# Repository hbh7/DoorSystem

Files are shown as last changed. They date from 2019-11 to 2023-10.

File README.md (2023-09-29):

# DoorSystem
Code to make a "smart" door locking system that you can use to unlock your door with your phone, as well as see the current weather conditions.

Designed by [hbh7](http://github.com/hbh7) and [alexboz](http://github.com/alexboz)

Features include:
- Non-intrusive design that doesn't require any modifications to the door itself. Perfect for dorms, apartments, and rentals. 
- Minimal hardware requirements - all you need is a Raspberry Pi, Arduino, and a servo. Optionally, you can get POE to USB adapters for long range power like as seen in the pictures. V3 also used a breadboard and capacitors to smooth out some voltage drop issues. You can also get the camera module and 3.5" touch screen for full functionality. 
- Peephole camera that can be broadcast over the network for remote viewing.
- Automatic unlocking followed by relocking after 15s using the timer button. 
- Background color shifts throughout the day to simulate day/night.
- Servo is disabled when the door is locked so that it can still be manually operated using the key, otherwise the servo would probably overpower your attempts.  

Potential areas of improvement:
- Convert 4th button to a camera viewer
- Run the servo closer to 7v instead of 5v for better performance.
- Single power cord option with a better POE adapter.
- Proper cases for everything to contain hardware and manage wires better.

Touch screen and web UI:
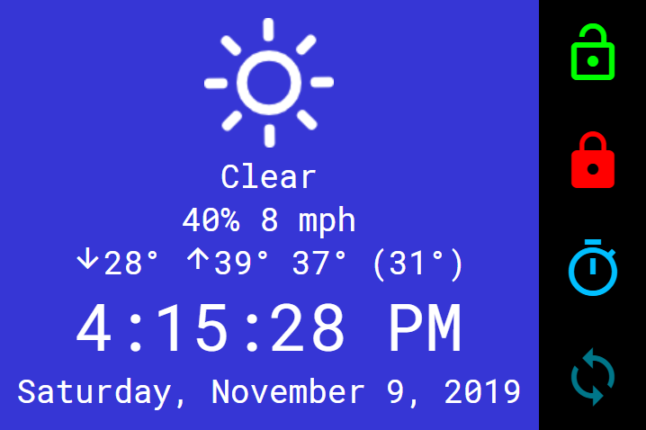
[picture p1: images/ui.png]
Touch screen and web UI


Implementation v3:
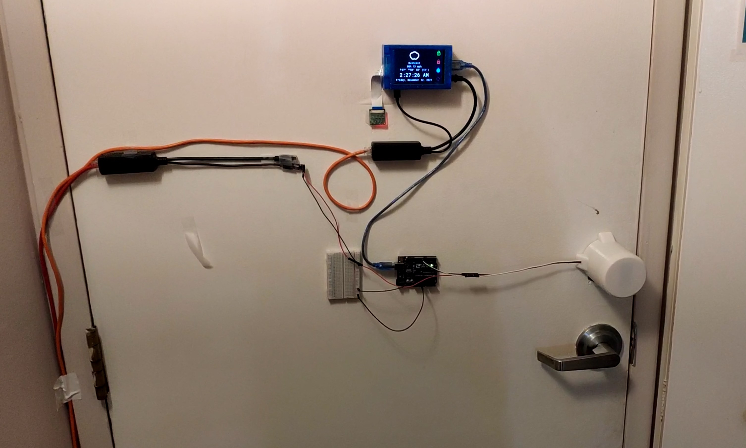
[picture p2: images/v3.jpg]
Implementation 3


Implementation v2:
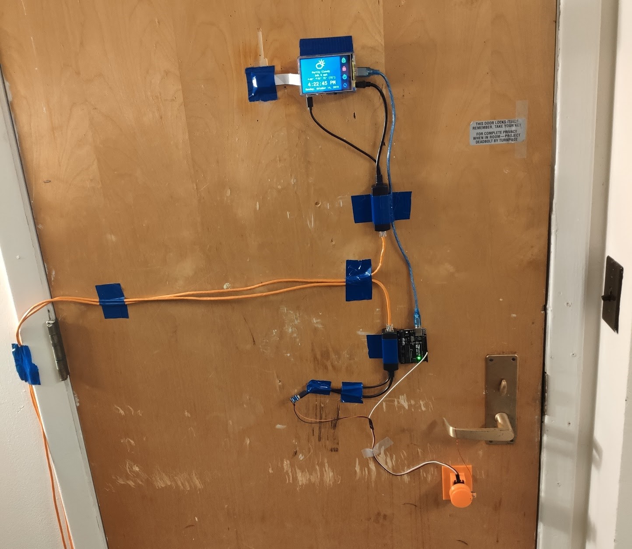
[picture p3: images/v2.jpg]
Implementation 2


Implementation v1:
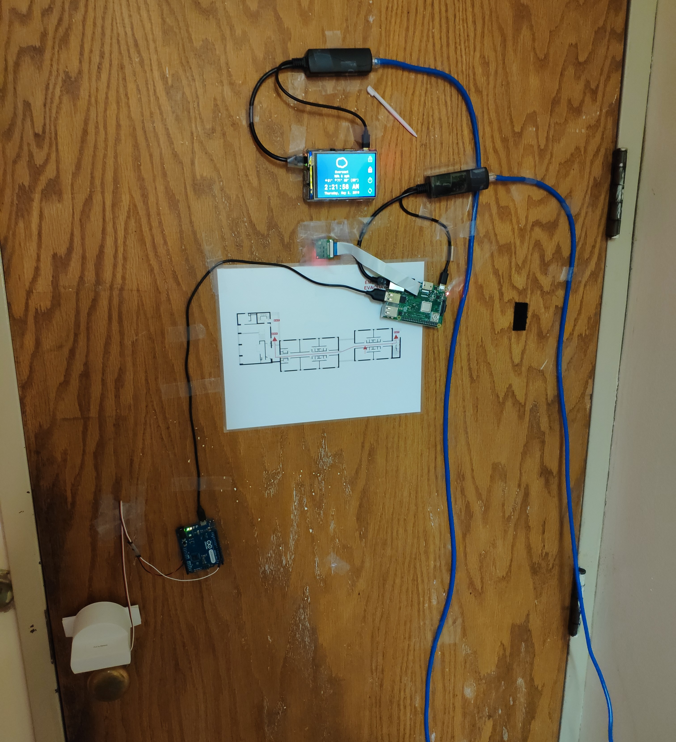
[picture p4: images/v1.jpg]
Implementation 1


## General setup directions
1. You'll want to acquire hardware and familiarize yourself with the software. The exact model of Pi, Arduino, servo, screen, camera, etc. does not matter.  
2. The Pi should run [doorlock-arduino-server.py](backend/doorlock-arduino-server.py) with Python 3, ideally started automatically with something like a systemd service. 
3. The Pi should also serve the html folder using a PHP-capable webserver like Apache. 
4. The Pi's desktop can be configured to automatically launch a fullscreen kiosk browser to the locally served files for display on the screen. This varies by desktop environment. 
5. The Arduino needs the code in [Arduino_Servo_Controller_Sketch.ino](Arduino_Servo_Controller_Sketch/Arduino_Servo_Controller_Sketch.ino) written to it. This enables serial communication to the Pi and drives the servo. Adjust the code as necessary to specify your servo pin and servo angle to match your door lock setup. This will take some trial and error. 
6. You'll also need to 3D model and print your own adapter to match your lock and servo. There are a bunch of examples in the [models](models) folder. 
7. For the webcam, I used https://github.com/jacksonliam/mjpg-streamer. You could use this, or a number of other libraries. This may vary based on your camera choice. 
8. Feel free to open an issue or something if you're having trouble. Good luck!

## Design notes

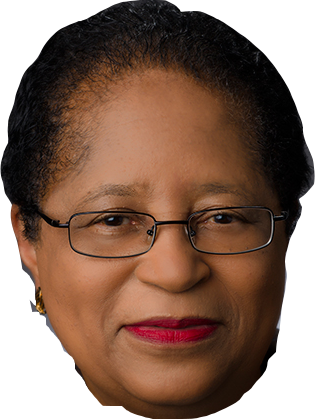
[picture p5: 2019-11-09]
html/shirley.png

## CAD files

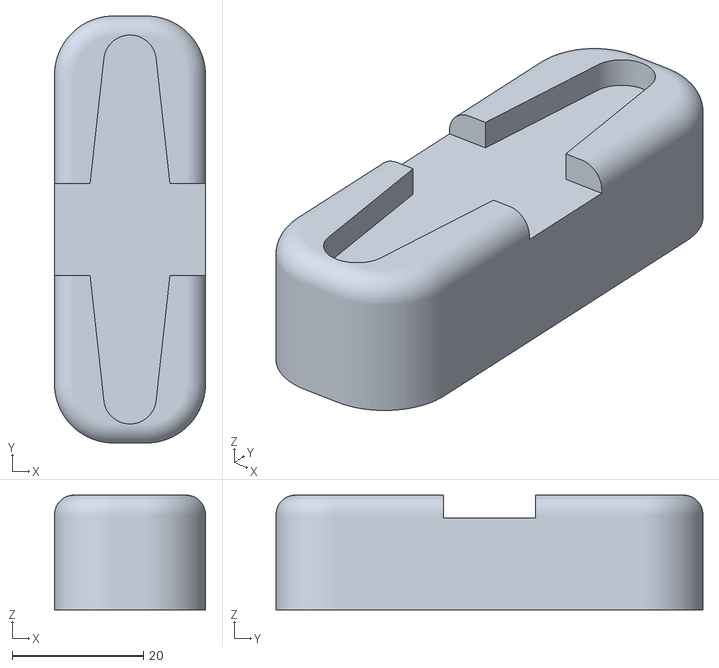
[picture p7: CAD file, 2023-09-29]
models/lock_adapter_modded.stl
23.0 x 65.0 x 17.5

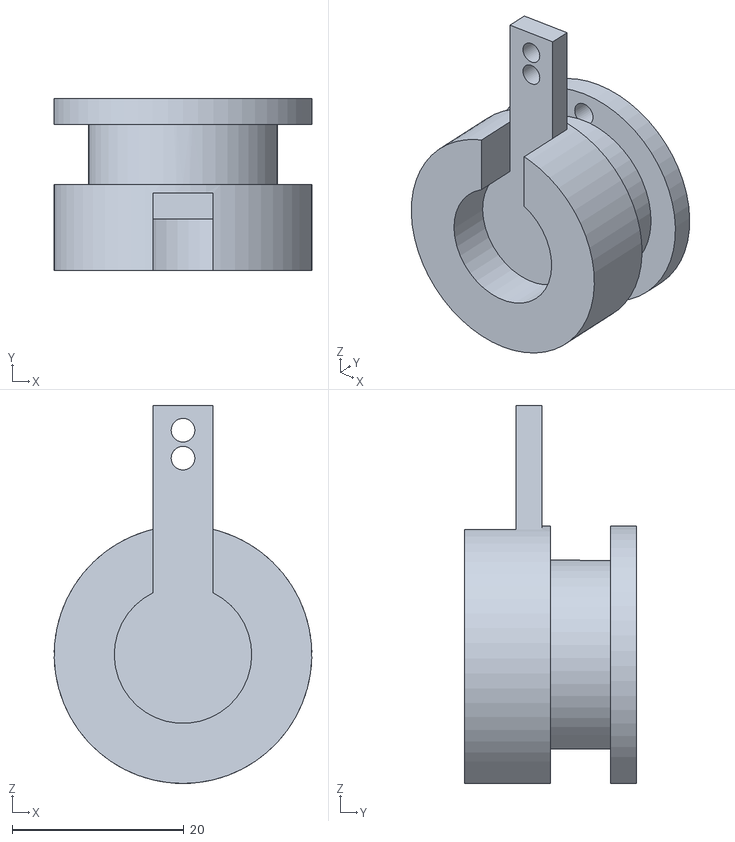
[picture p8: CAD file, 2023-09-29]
models/Servo Wheel 3.STL
30.0 x 20.0 x 44.0

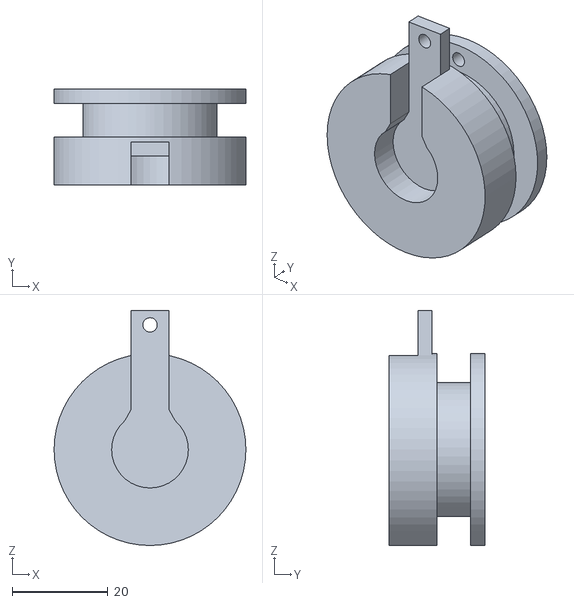
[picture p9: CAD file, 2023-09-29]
models/Servo Wheel 6.STL
40.0 x 20.0 x 49.0

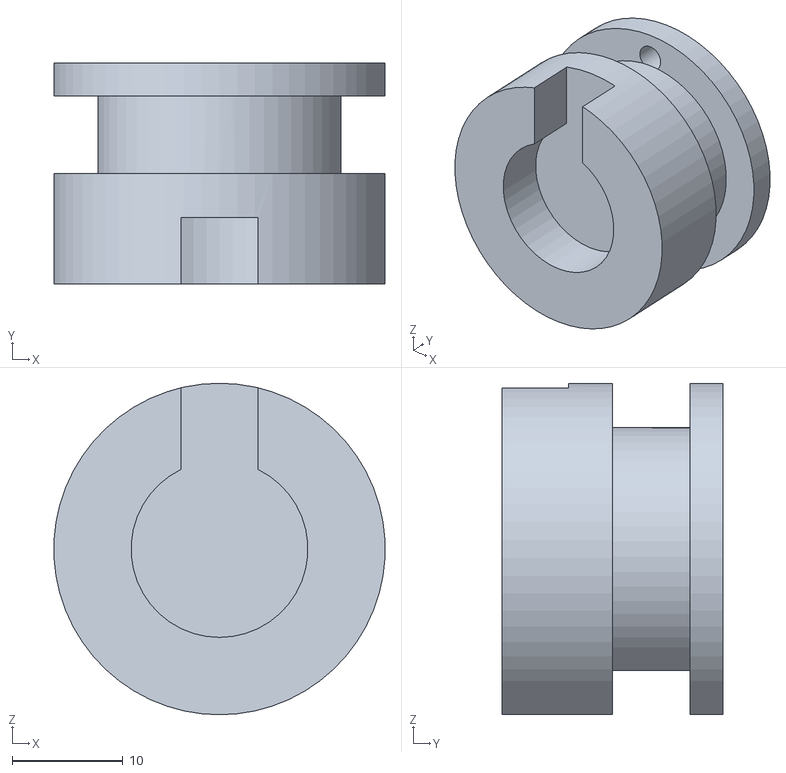
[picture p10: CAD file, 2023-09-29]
models/Servo Wheel 2.STL
30.0 x 20.0 x 30.0

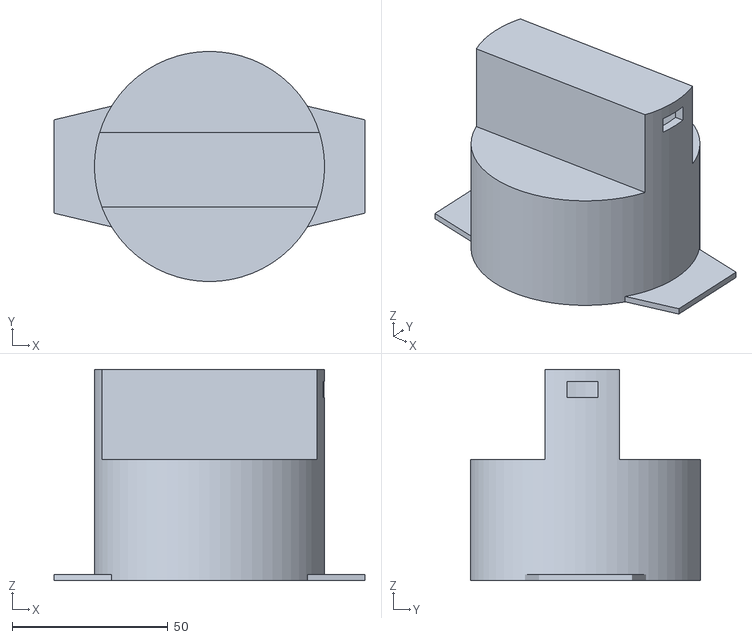
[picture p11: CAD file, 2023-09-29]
models/Door Adapter.stl
100.0 x 74.0 x 68.0

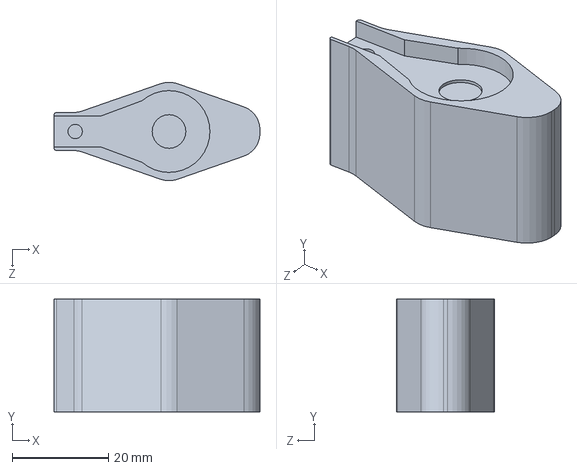
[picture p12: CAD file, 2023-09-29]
models/Door Lock Adapter.SLDPRT
42.8 x 23.4 x 20.4 mm

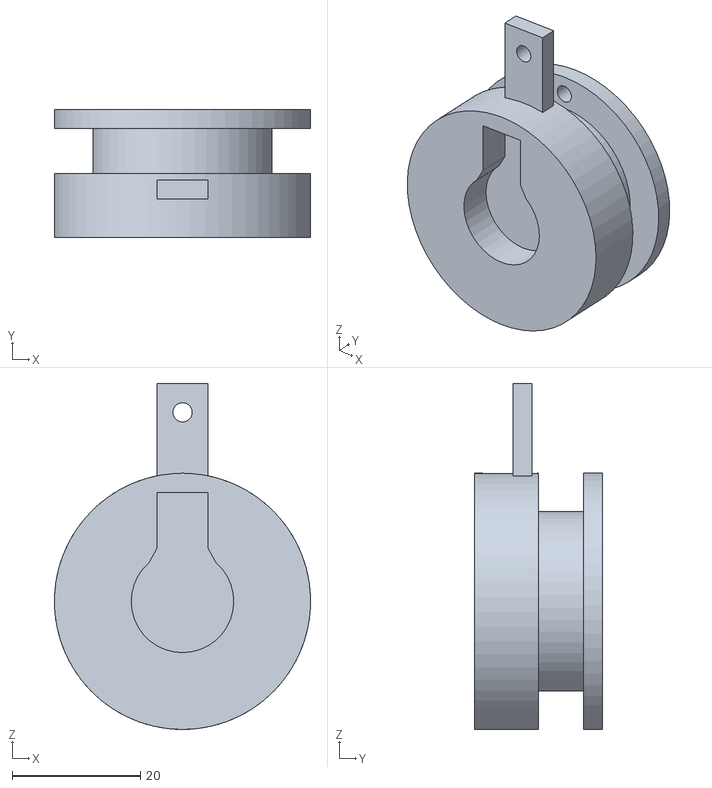
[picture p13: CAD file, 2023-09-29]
models/Servo Wheel 5.STL
40.0 x 20.0 x 54.0

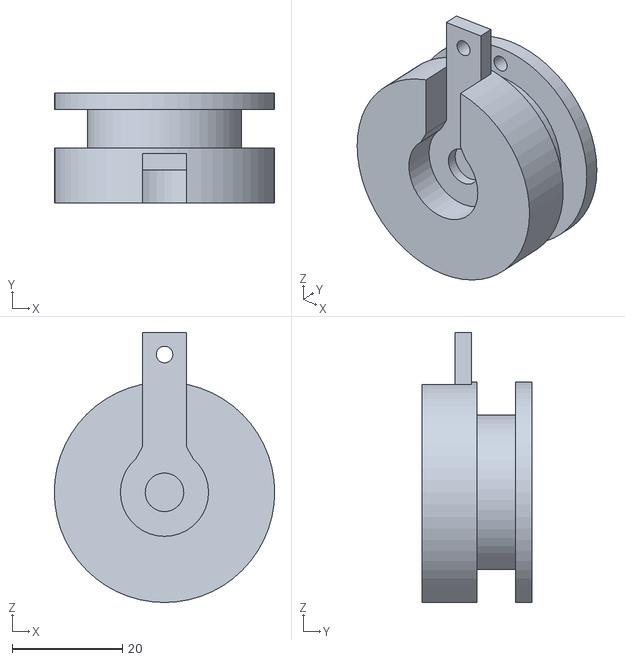
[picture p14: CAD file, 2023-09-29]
models/Servo Wheel 7.STL
40.0 x 20.0 x 49.0

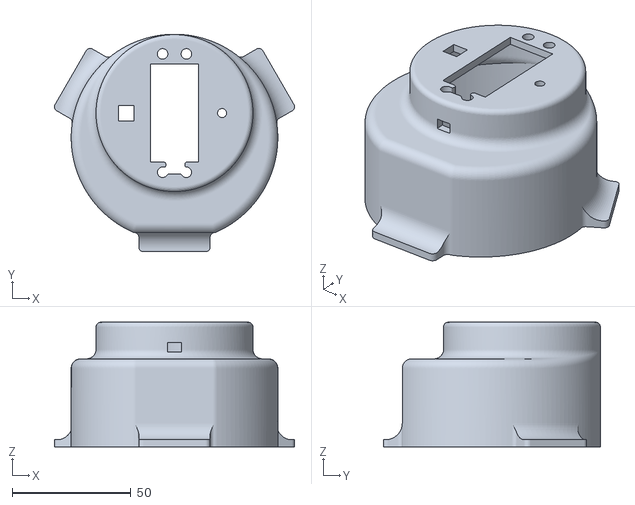
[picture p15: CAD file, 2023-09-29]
models/lock_housing.stl
100.9 x 91.5 x 52.4

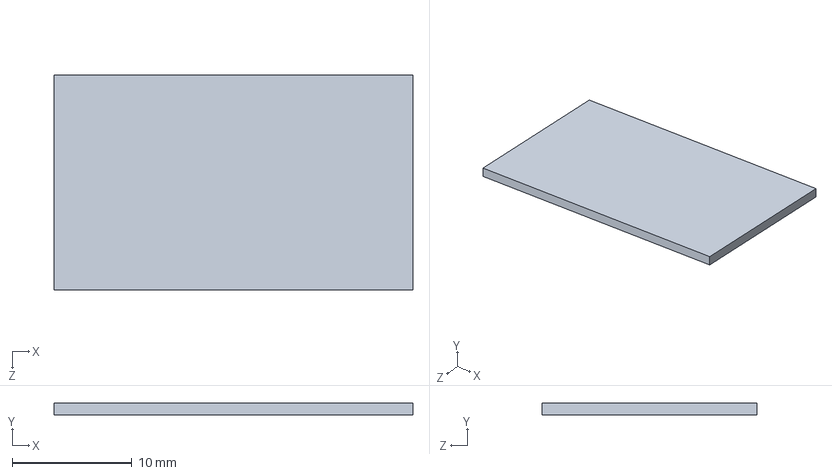
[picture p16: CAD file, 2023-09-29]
models/Pi Screen Spacer.SLDPRT
30.0 x 1.00 x 18.0 mm

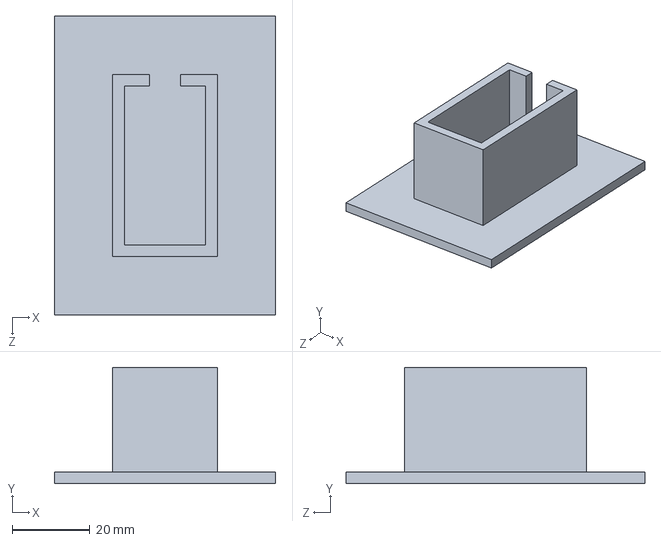
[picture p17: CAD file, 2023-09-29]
models/Servo Mount 3.SLDPRT
57.0 x 30.0 x 77.0 mm

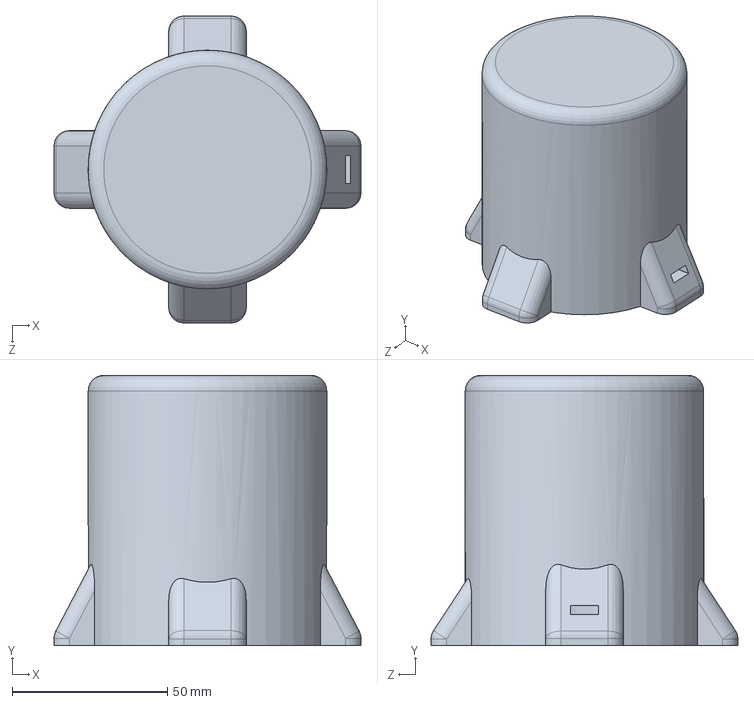
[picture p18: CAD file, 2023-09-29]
models/Servo Housing.SLDPRT
98.8 x 87.0 x 98.8 mm

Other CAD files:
models/Servo Mount 2.SLDPRT
models/Servo Mount.SLDPRT
models/Servo Wheel 4.STL
models/Servo Mount 3-2.STL
models/Servo Mount 2 2.SLDPRT
models/lock_adapter.stl
models/Cup.stl
models/Door Lock Adapter.STL
models/Door Lock.SLDPRT
models/Part4.SLDPRT
models/Pi Screen Spacer.STL
models/Servo Housing.STL
models/Servo Mount 3.STL
models/Servo Wheel 1.STL
models/Servo Wheel.SLDPRT
models/lock_housing 001.3dm
models/lock_housing 002.3dm
models/lock_housing 003.3dm
models/lock_housing 004.3dm
models/lock_housing.3dm

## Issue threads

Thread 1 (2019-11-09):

Occasional temperature rounding error

hbh7, 2019-11-09:

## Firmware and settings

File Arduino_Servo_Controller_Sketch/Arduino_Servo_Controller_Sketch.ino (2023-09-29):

#include <Servo.h>              //Servo library
 
Servo servo;        //initialize a servo object for the connected servo  
                
int angle = 0;    



void setup() {
  // put your setup code here, to run once:
  
  Serial.begin(9600);           // set up Serial library at 9600 bps
  while (!Serial) {
  ; // wait for serial port to connect. Needed for native USB port only
  }
  Serial.setTimeout(100);
  pinMode(LED_BUILTIN, OUTPUT);
  enableServo();
  closeDoor();
  disableServo();
}

void loop() {

  if (Serial.available() > 0) {
    // read the incoming byte:
    Serial.setTimeout(100);
    int incomingNumber = Serial.parseInt();
    Serial.setTimeout(10);
    Serial.parseInt();

    enableServo();
    if(incomingNumber == 1) {
      openDoor();
    } else {
      closeDoor();
    }
  }
}

void enableServo() {
  servo.attach(9);
  delay(10);
}

void disableServo() {
  servo.detach();
}

void openDoor() {
  Serial.println("Opening door");
  digitalWrite(LED_BUILTIN, HIGH);   // turn the LED on (HIGH is the voltage level)
  servo.write(80);
  delay(1500);
}


void closeDoor() {
  Serial.println("Closing door");
  digitalWrite(LED_BUILTIN, LOW);   // turn the LED on (HIGH is the voltage level)
  servo.write(180);
  delay(1500);
  disableServo();
}

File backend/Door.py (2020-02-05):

from enum import Enum
import time
import serial
import threading

class State(Enum):
    NORMAL = 0
    TIMER = 1
    SWEEP = 2


class LockState(Enum):
    MYSTERY = -1
    UNLOCKED = 0
    LOCKED = 1


class Door:
    state = State.NORMAL
    lockState = LockState.MYSTERY
    lockTimeout = 0

    def __init__(self, serialport):
        self.ser = serial.Serial(serialport, 9600)
        threading.Thread(target=self.watchLockStatus).start()

    def watchLockStatus(self):
        while True:
            if self.lockTimeout != 0:
                if time.time() > self.lockTimeout:
                    print("Auto lock timeout reached")
                    self.lock_control()
                else:
                    print("Auto lock in " + str(self.lockTimeout-time.time()) + " seconds")
            time.sleep(1)

    def lock_control(self):
        print("Lock")
        self.ser.write('0'.encode())
        self.state = State.NORMAL
        self.lockState = LockState.LOCKED
        # Clear auto lock timeout
        self.lockTimeout = 0

    def unlock_control(self):
        print("Unlock")
        self.ser.write('1'.encode())
        self.state = State.NORMAL
        self.lockState = LockState.UNLOCKED
        # Auto lock after 15 minutes
        self.lockTimeout = time.time() + (60*15)

    def enforce_state(self):
        if self.state == State.NORMAL:
            if self.lockState == LockState.UNLOCKED:
                self.unlock_control()
            elif self.lockState == LockState.LOCKED:
                self.lock_control()

    def timer(self, delay):
        print("Timer")
        if self.state == State.TIMER:  # Check if in timer state. If so, cancel it.
            self.state = State.NORMAL
            return
        self.state = State.TIMER
        self.unlock_control()
        self.lockTimeout = time.time() + delay

    def sweep(self, iterations):
        print("Sweep")
        if self.state == State.SWEEP:  # Check if in sweep state. If so, cancel it.
            self.state = State.NORMAL
            return
        self.state = State.SWEEP
        while self.state == State.SWEEP:
            for i in range(0, iterations):
                self.unlock_control()
                time.sleep(3)
                self.lock_control()
                time.sleep(3)
            self.state = State.NORMAL

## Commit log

2019-11-09 Current codebase
2020-02-04 Changed sweep timer to work with current door system
2020-02-05 Fixed timer not timing out and locking, changed to 15s timer
    [Door.py, doorlock-arduino-server.py]
2023-09-29 Added additional resources and info necessary to set up the project
    [Cup.stl, Door Adapter.stl, Door Lock Adapter.SLDPRT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]
